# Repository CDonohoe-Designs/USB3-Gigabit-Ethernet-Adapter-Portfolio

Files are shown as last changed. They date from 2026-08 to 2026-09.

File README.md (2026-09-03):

# USB 5 Gbit/s to Gigabit Ethernet Adapter

LAN7800-based **USB 5 Gbit/s (USB 3.2 Gen 1, formerly USB 3.1 Gen 1)** to Gigabit Ethernet adapter designed in **Altium Designer** as a high-speed hardware and PCB design portfolio project.

<p align="center">
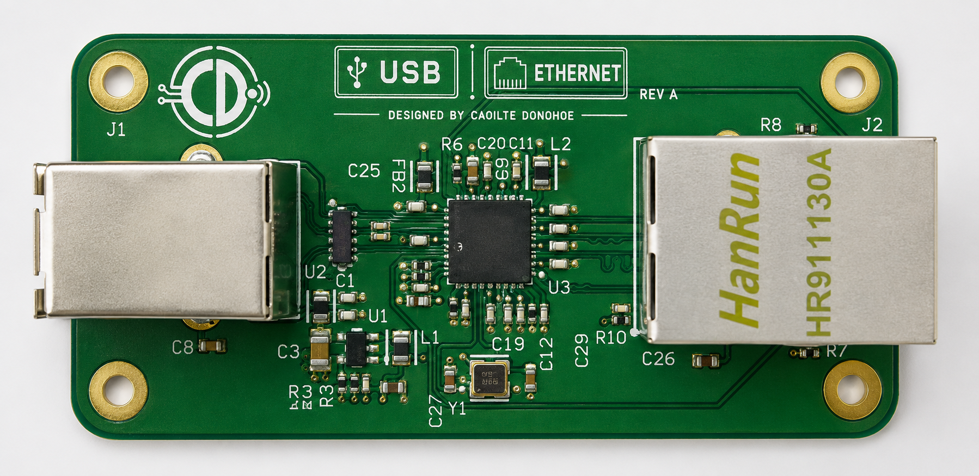
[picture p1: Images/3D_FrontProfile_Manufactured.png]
LAN7800 USB to Gigabit Ethernet adapter 3D view
  
</p>

## 2-Minute Engineering Review

I designed this project as a complete **high-speed digital hardware exercise**, taking the design from architecture and schematic capture through controlled-impedance PCB layout, rule-driven verification and fabrication outputs.

### Engineering focus

- **High-speed interfaces** — USB 5 Gbit/s SuperSpeed, USB 2.0 and Gigabit Ethernet on the same board
- **Signal integrity** — 90 Ω USB and 100 Ω Ethernet differential-impedance targets
- **Return-path control** — continuous reference structure and deliberate avoidance of unnecessary layer transitions
- **Constraint-driven layout** — Altium net classes, differential-pair classes, matched-length rules and layer restrictions
- **Power integrity** — local decoupling and separate LAN7800 supply routing/pours
- **Protection / EMC intent** — ESD protection close to external interfaces and controlled current-return paths
- **Manufacturing readiness** — fabrication drawing, Gerber X2, NC Drill and final Altium DRC

### Quick review

- **[Complete schematic](Docs/LAN7800_USB_Ethernet_RevA_Schematic.pdf)**
- **[PCB top layout](Images/PCB_Layout_Top.PNG)**
- **[PCB bottom / power layout](Images/PCB_Layout_Bottom.PNG)**
- **[High-speed design rules](Images/Design_Rules/)**
- **[Final DRC result](Images/DRC.PNG)**
- **[Fabrication drawing](Docs/LAN7800_USB_Ethernet_RevA_Fabrication.PDF)**
- **[Editable Altium source](Hardware/Altium/)**

> **Current status:** schematic, PCB layout, design-rule verification and manufacturing outputs are complete. The repository presents the design and fabrication package as portfolio evidence rather than claiming physical product validation.

---

## Project Overview

I designed this board to convert a **USB 5 Gbit/s host connection** to **10/100/1000BASE-T Ethernet** using the Microchip **LAN7800** USB-to-Ethernet controller.

I developed the project to demonstrate the complete hardware design process rather than schematic capture alone, including component selection, power architecture, controlled-impedance routing, high-speed PCB constraints, grounding and return-path control, manufacturability rules, DRC, and fabrication documentation.

### Key design features

- Microchip **LAN7800** USB-to-Gigabit-Ethernet controller
- USB 2.0 and USB 5 Gbit/s SuperSpeed interfaces
- Gigabit Ethernet MDI interface to RJ45 MagJack
- **4-layer PCB** with dedicated internal reference structure
- **90 Ω differential impedance** target for USB
- **100 Ω differential impedance** target for Gigabit Ethernet
- Dedicated Altium **net classes, differential-pair classes and routing rules**
- Length matching and controlled pair spacing for high-speed interfaces
- Separate power routing/pours for the LAN7800 supply rails
- ESD/protection components positioned close to the external interfaces
- Fabrication drawing and manufacturing output preparation
- Final PCB checked using Altium DRC

## High-Speed Design Approach

I treated the PCB as a **high-speed design**, with the layout driven by signal-integrity and return-path requirements rather than by simple point-to-point connectivity.

The main design methods I used were:

- **Controlled impedance:** dedicated Altium impedance profiles were created for 90 Ω USB and 100 Ω Ethernet differential routing.
- **Differential-pair classes:** USB 2.0, USB SuperSpeed and Ethernet MDI signals were separated into dedicated classes so interface-specific constraints could be applied consistently.
- **Length matching:** matched-length rules were used to control skew within high-speed differential pairs, with separate Ethernet pair-to-pair matching constraints.
- **Continuous reference planes:** the high-speed signals are routed primarily on the outer signal layer over an adjacent solid reference plane.
- **Layer restrictions:** high-speed classes were constrained to intended routing layers to avoid unnecessary layer changes and reference-plane discontinuities.
- **Controlled spacing and clearance:** dedicated rules were used for pair geometry, pair-to-pair spacing and clearance from unrelated copper.
- **Via control:** separate via styles were defined for general and higher-current power routing.
- **Power integrity:** local power pours, short decoupling paths and large ground regions were used around the LAN7800 and its regulators.
- **Manufacturing constraints:** minimum annular ring, drilled-hole, solder-mask and silkscreen rules were included in the PCB rule set.
- **Rule-driven verification:** Altium's PCB Rules and Constraints system and DRC were used to check that the physical implementation remained consistent with the design intent.

## PCB Layout

### Top side

I used the top layer for the principal signal routing, including the USB and Ethernet differential interfaces and the LAN7800 support circuitry.

<p align="center">
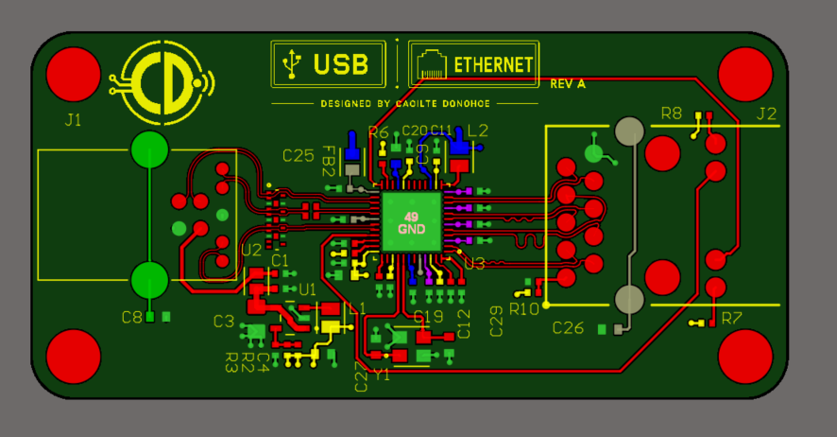
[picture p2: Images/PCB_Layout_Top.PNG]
Top PCB layout
  
</p>

### Bottom side — power and ground distribution

I used the bottom side for local power distribution together with a broad GND copper pour. The internal reference structure provides the primary high-speed return path.

<p align="center">
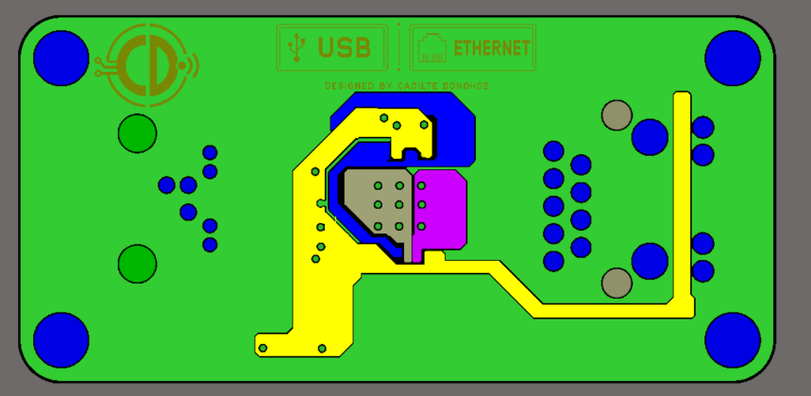
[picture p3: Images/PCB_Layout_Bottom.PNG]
Bottom PCB layout showing power and ground pours
  
</p>

## Schematic

The design is split into two functional sheets: **USB/power** and **LAN7800/Ethernet**.

<p align="center">
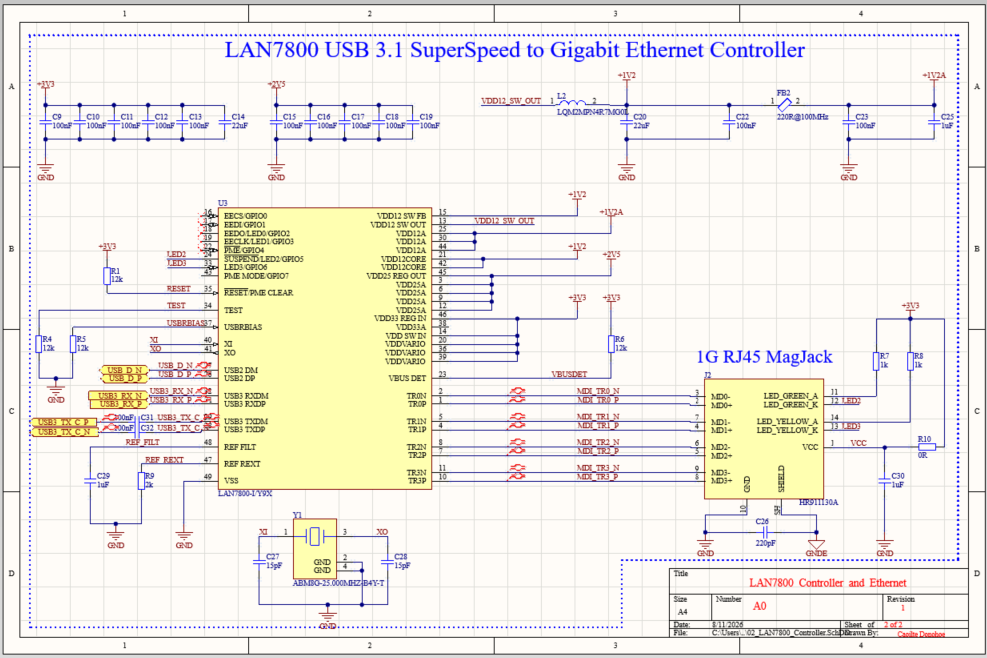
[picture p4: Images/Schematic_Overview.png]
LAN7800 and Ethernet schematic overview
  
</p>

<details>
<summary><b>View USB and power schematic overview</b></summary>

<p align="center">
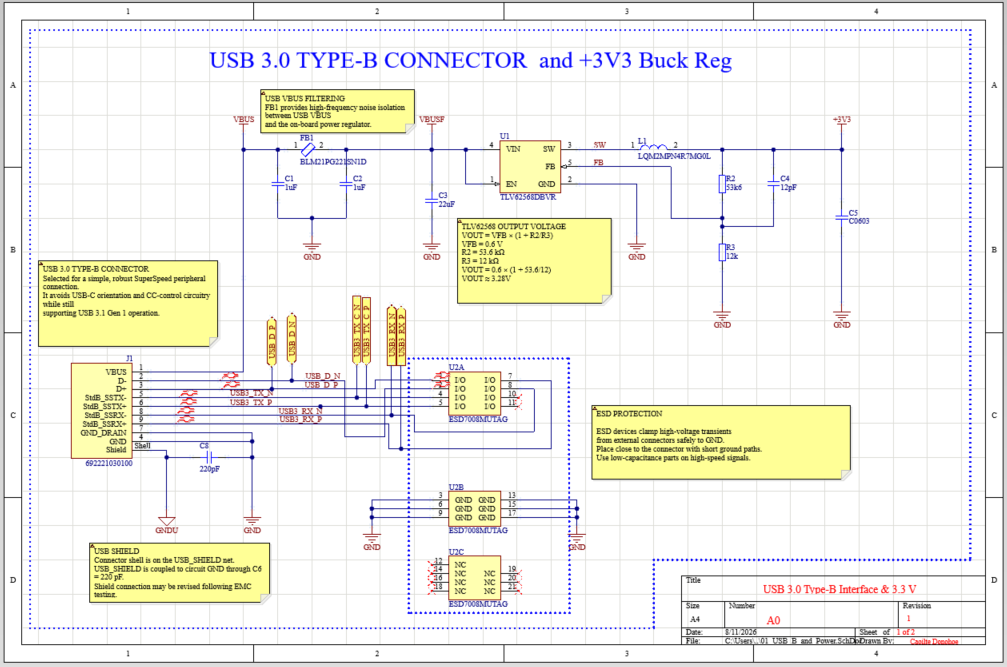
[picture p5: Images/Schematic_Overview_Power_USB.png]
USB and power schematic overview
  
</p>

</details>

**[View the complete schematic PDF](Docs/LAN7800_USB_Ethernet_RevA_Schematic.pdf)**

**[View the Rev A fabrication drawing](Docs/LAN7800_USB_Ethernet_RevA_Fabrication.PDF)**

**[Download the Rev A fabrication package](Manufacturing/LAN7800_USB_Ethernet_RevA_Fabrication.zip)**  
Gerber X2, NC Drill and fabrication documentation.

## Design Verification

I ran a final Altium **Design Rule Check** against the configured PCB rule set after completing the layout and copper pours. The final report shows **0 warnings and 0 rule violations**.

<p align="center">
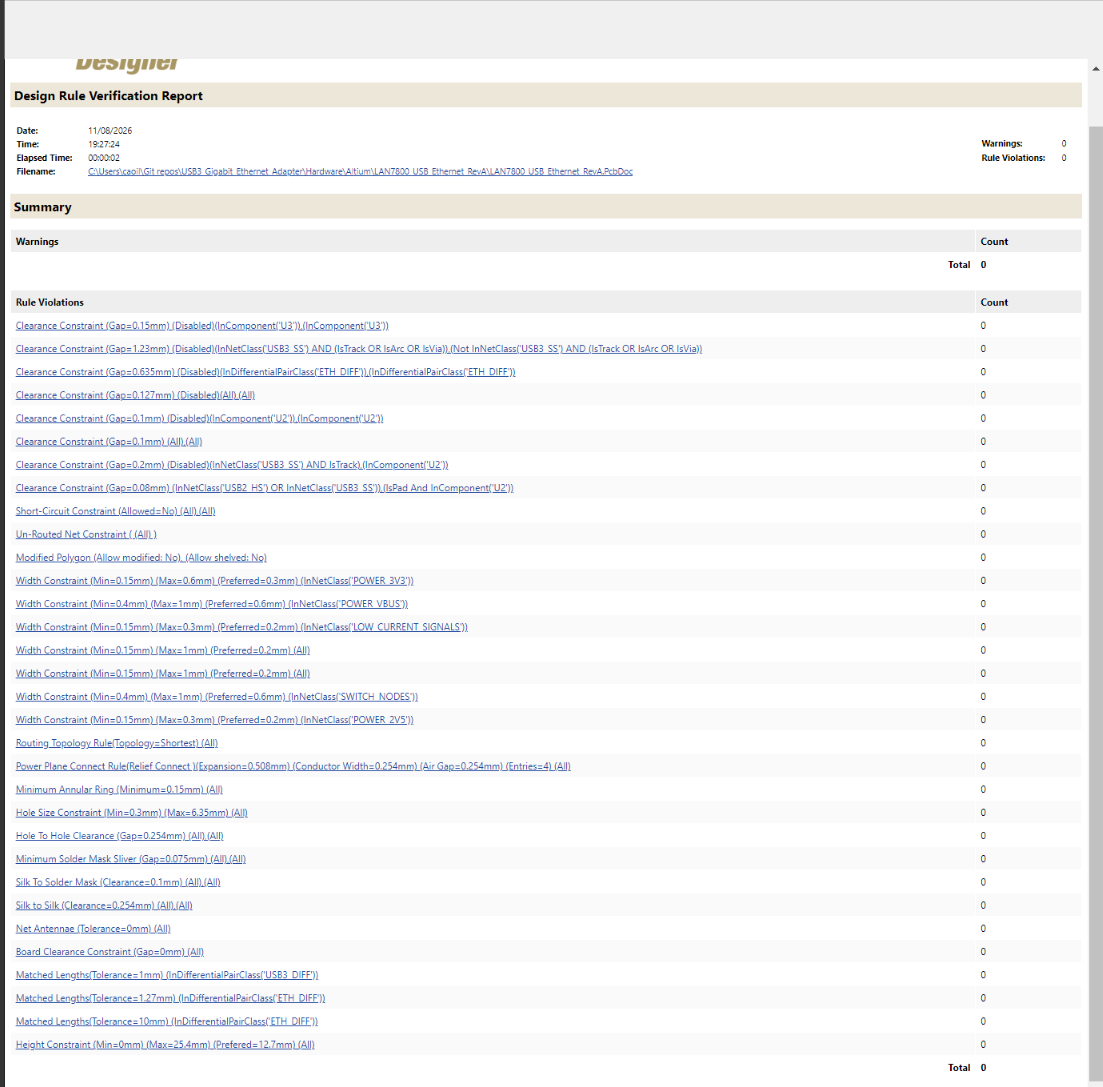
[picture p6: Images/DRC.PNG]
Altium final DRC report showing zero warnings and zero rule violations
  
</p>

## Altium Design Rules

I used a rule-driven approach rather than manually routing each interface with ad-hoc settings. Representative rule configuration is shown below.

<details>
<summary><b>View high-speed stack-up, impedance and rule configuration</b></summary>

### Layer stack

<p align="center">
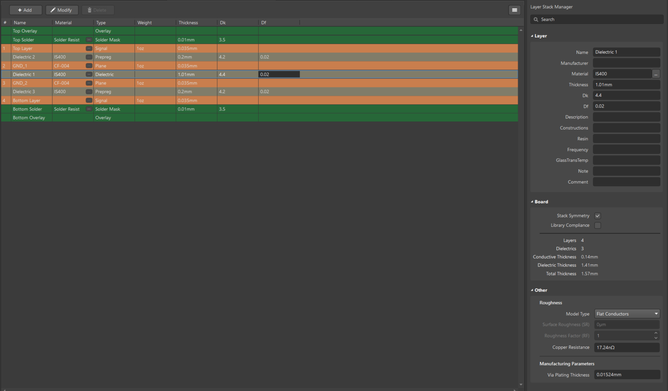
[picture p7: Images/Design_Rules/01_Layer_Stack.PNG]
4-layer PCB stack-up
  
</p>

### Controlled-impedance profiles

<p align="center">
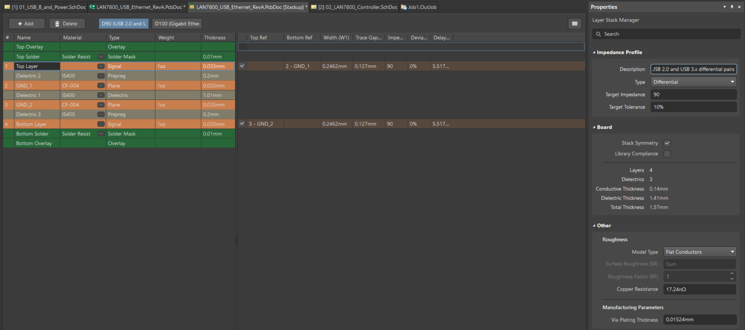
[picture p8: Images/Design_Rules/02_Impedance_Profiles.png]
USB and Ethernet impedance profiles
  
</p>

### Net classes

<p align="center">
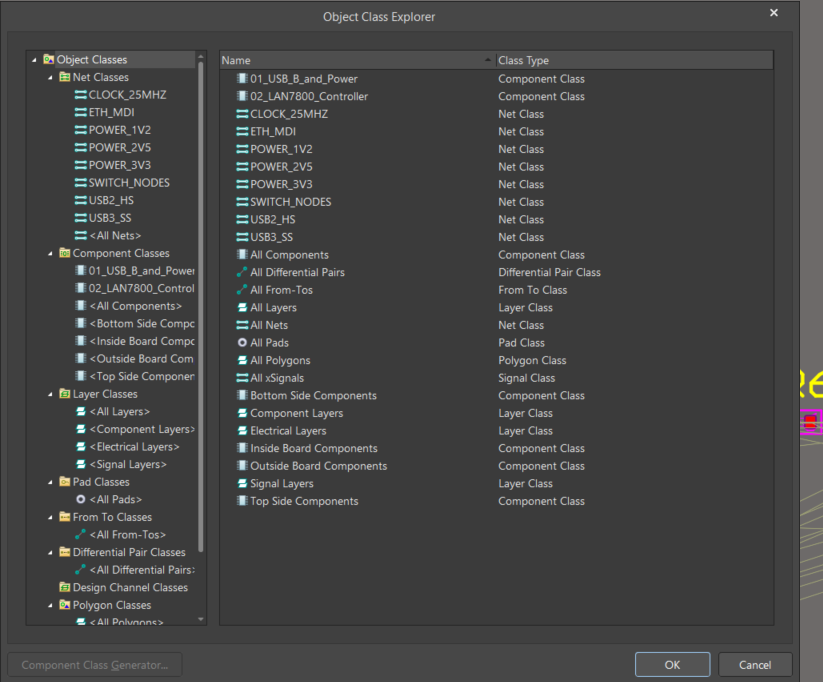
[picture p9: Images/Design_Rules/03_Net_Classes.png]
Altium net classes
  
</p>

### Differential-pair routing rules

<p align="center">
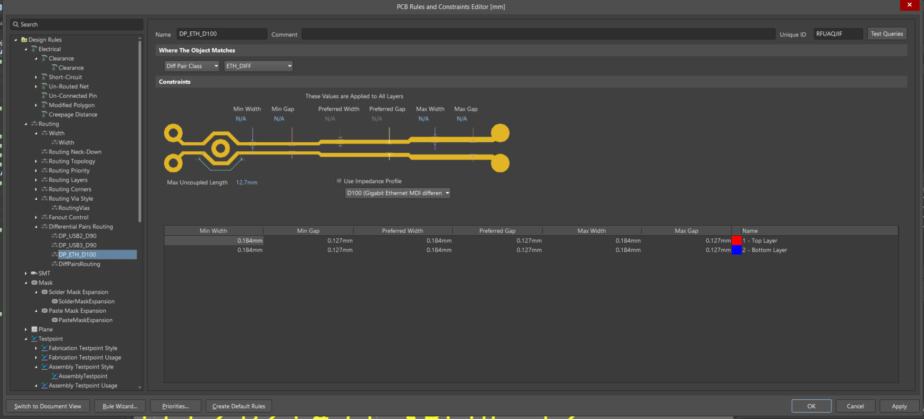
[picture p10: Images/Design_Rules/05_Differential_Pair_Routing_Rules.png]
Differential pair routing rules
  
</p>

### Matched-length rules

<p align="center">
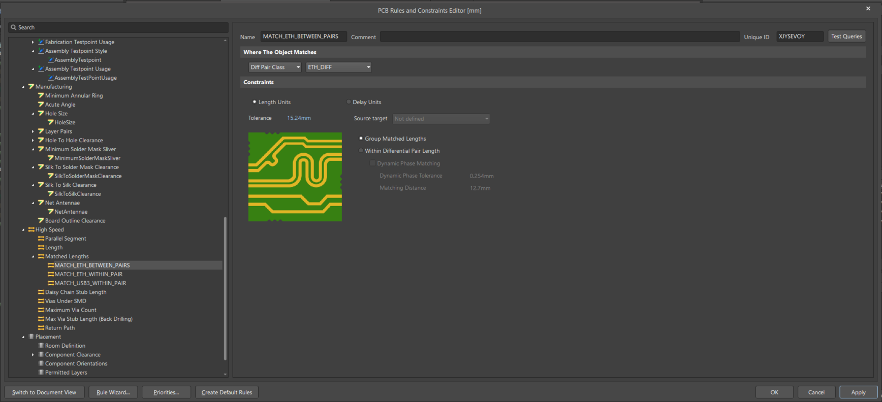
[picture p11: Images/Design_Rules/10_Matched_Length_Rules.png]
Matched length rules
  
</p>

</details>

## Source portability

I keep the repository focused on the project-owned source required to inspect the design: the Altium project, schematic sheets, PCB and project PCB library. Local-only references to downloaded component libraries, generated outputs and unrelated files are intentionally excluded from the portfolio project.

Manufacturer CAD packages are not redistributed here. The instantiated schematic and PCB data remain available in the project design files for review.

## Repository Contents

```text
Hardware/Altium/   Editable Altium schematic and PCB source
Docs/              Schematic and fabrication PDFs
Images/            PCB, schematic and selected design-rule images
Manufacturing/     Rev A Gerber X2 and NC Drill fabrication package
```

**Designed by Caoilte Donohoe**

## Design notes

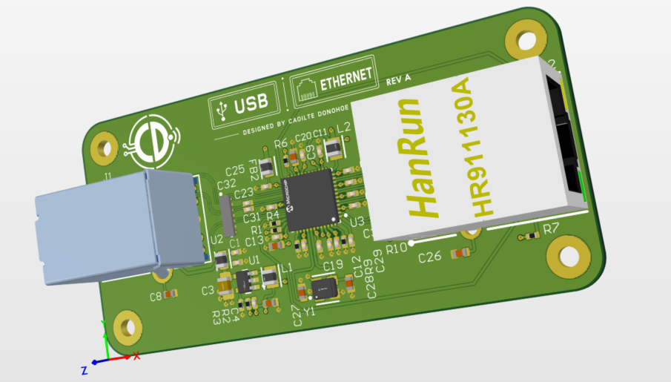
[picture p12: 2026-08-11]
Images/PCB_3D.PNG

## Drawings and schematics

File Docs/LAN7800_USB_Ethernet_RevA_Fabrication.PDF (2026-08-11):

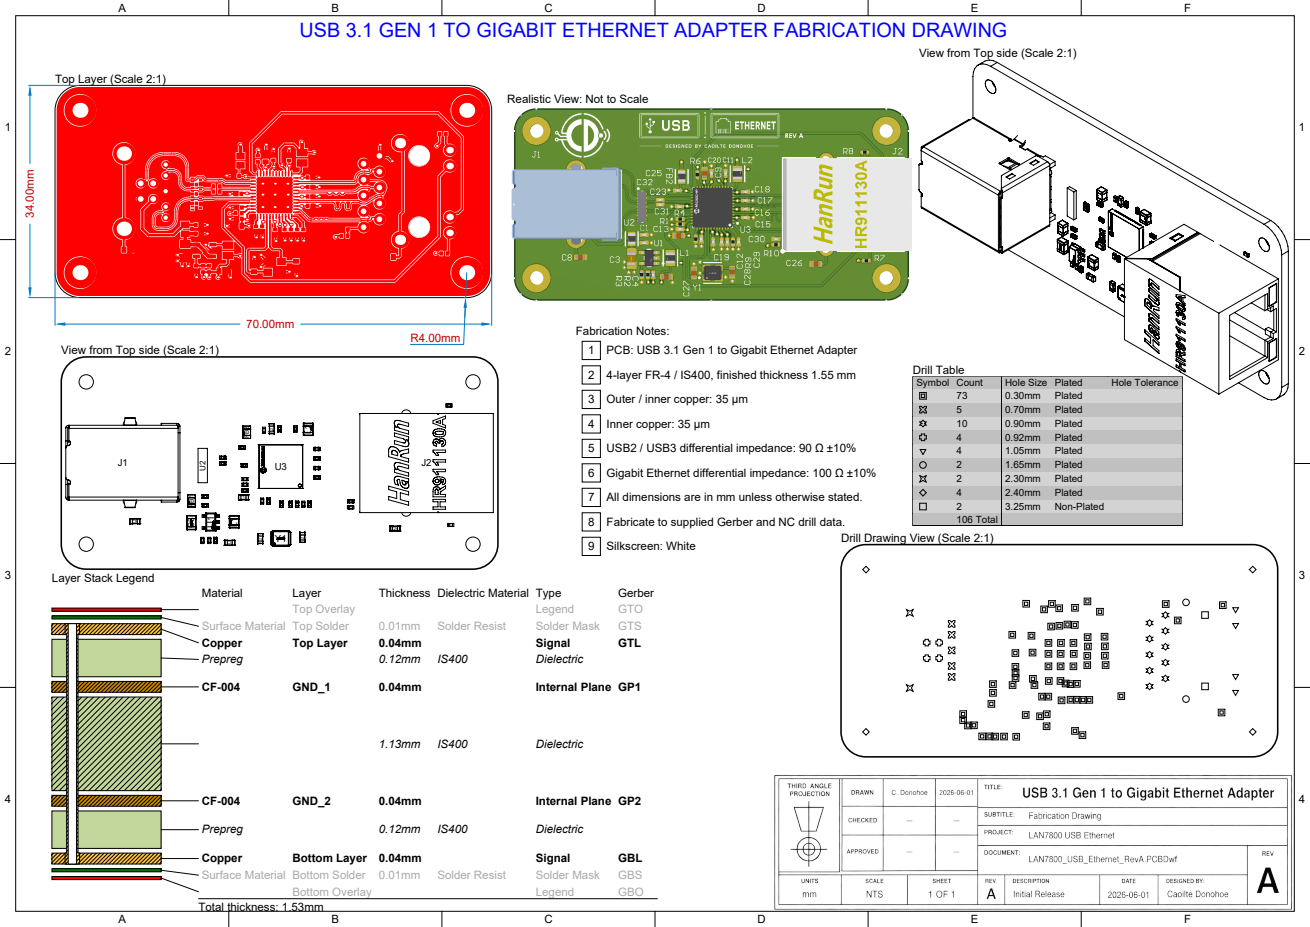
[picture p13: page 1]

USB 3.1 GEN 1 TO GIGABIT ETHERNET ADAPTER FABRICATION DRAWING

View from Top side (Scale 2:1)

Realistic View: Not to Scale

Symbol | Count | Hole Size | Plated | Hole Tolerance

73 | 0.30mm | Plated
5 | 0.70mm | Plated
10 | 0.90mm | Plated
4 | 0.92mm | Plated

2 | 1.65mm | Plated
2 | 2.30mm | Plated
4 | 2.40mm | Plated
2 | 3.25mm | Non-Plated
106 Total

Drill Drawing View (Scale 2:1)

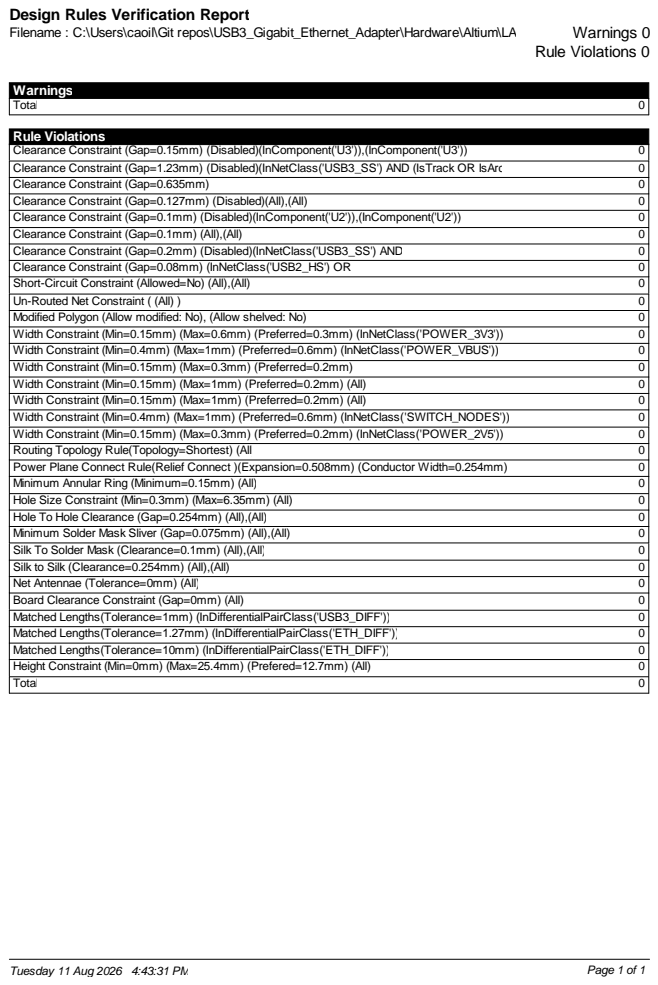
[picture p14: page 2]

Design Rules Verification Report

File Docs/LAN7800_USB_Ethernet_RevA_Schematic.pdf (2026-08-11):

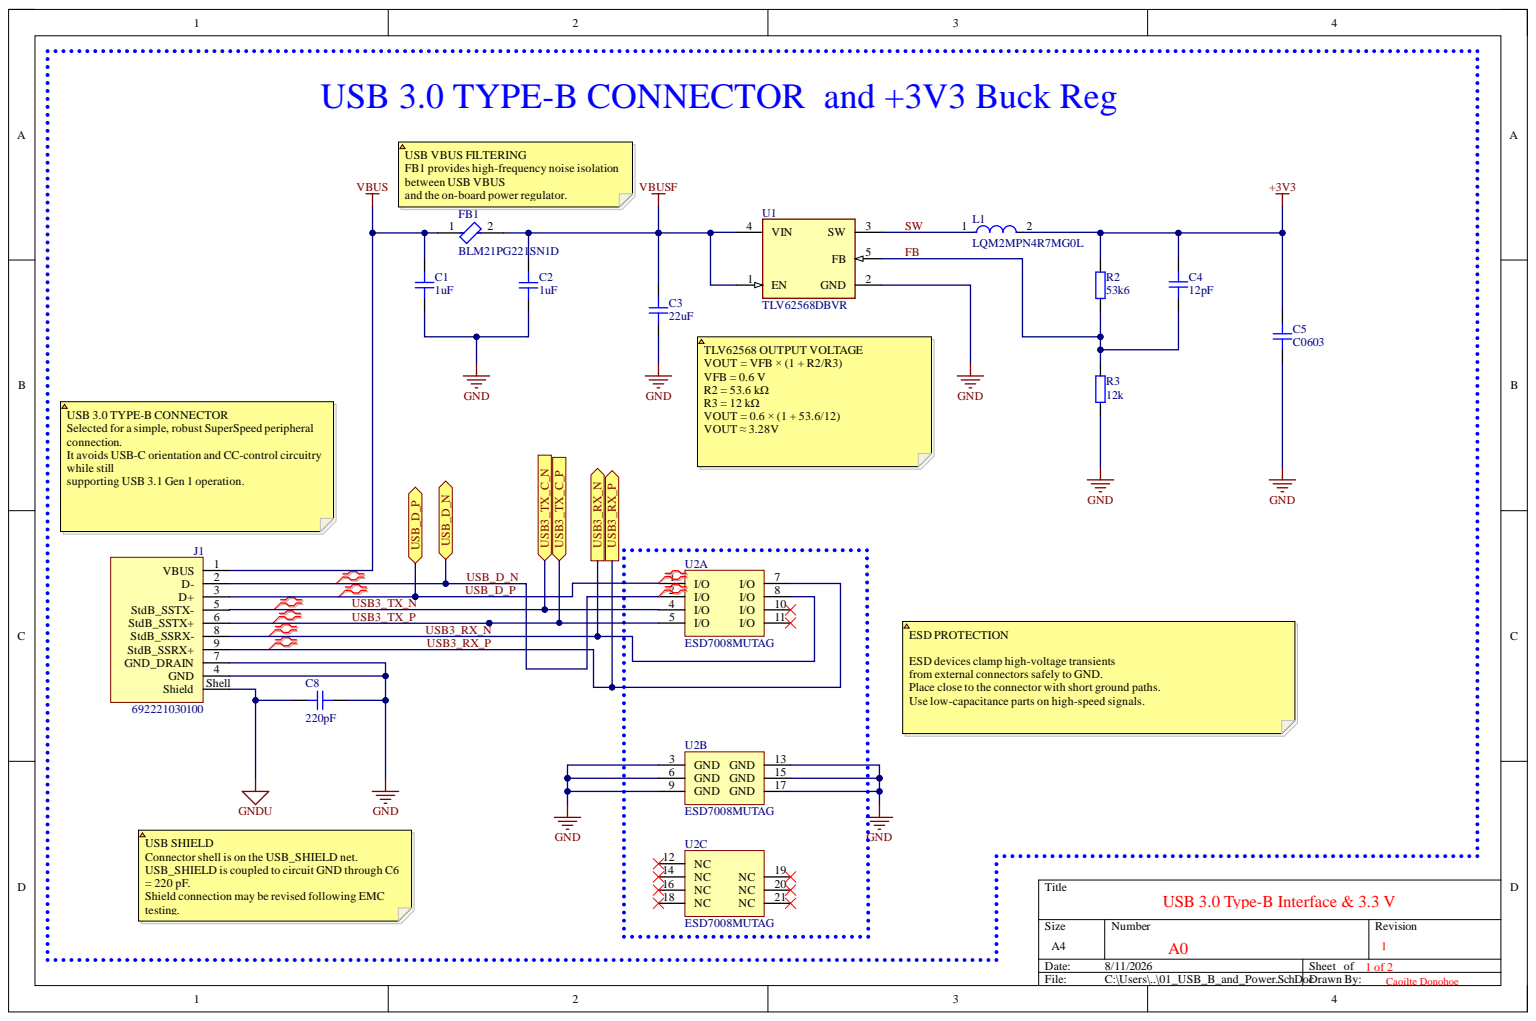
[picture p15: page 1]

USB 3.0 TYPE-B CONNECTOR and +3V3 Buck Reg

3 | USB_ D _P | | | 2 | | 8
5 USB3 _ T X_N | | | 4 | | 1 0
6 USB3 _ T X_P | | | 5 | | 1 1
8 USB3 _RX _N
9 USB3 _RX _P | | ESD 7 0 0 8MU TA

6 | 1 5
9 | 1 7

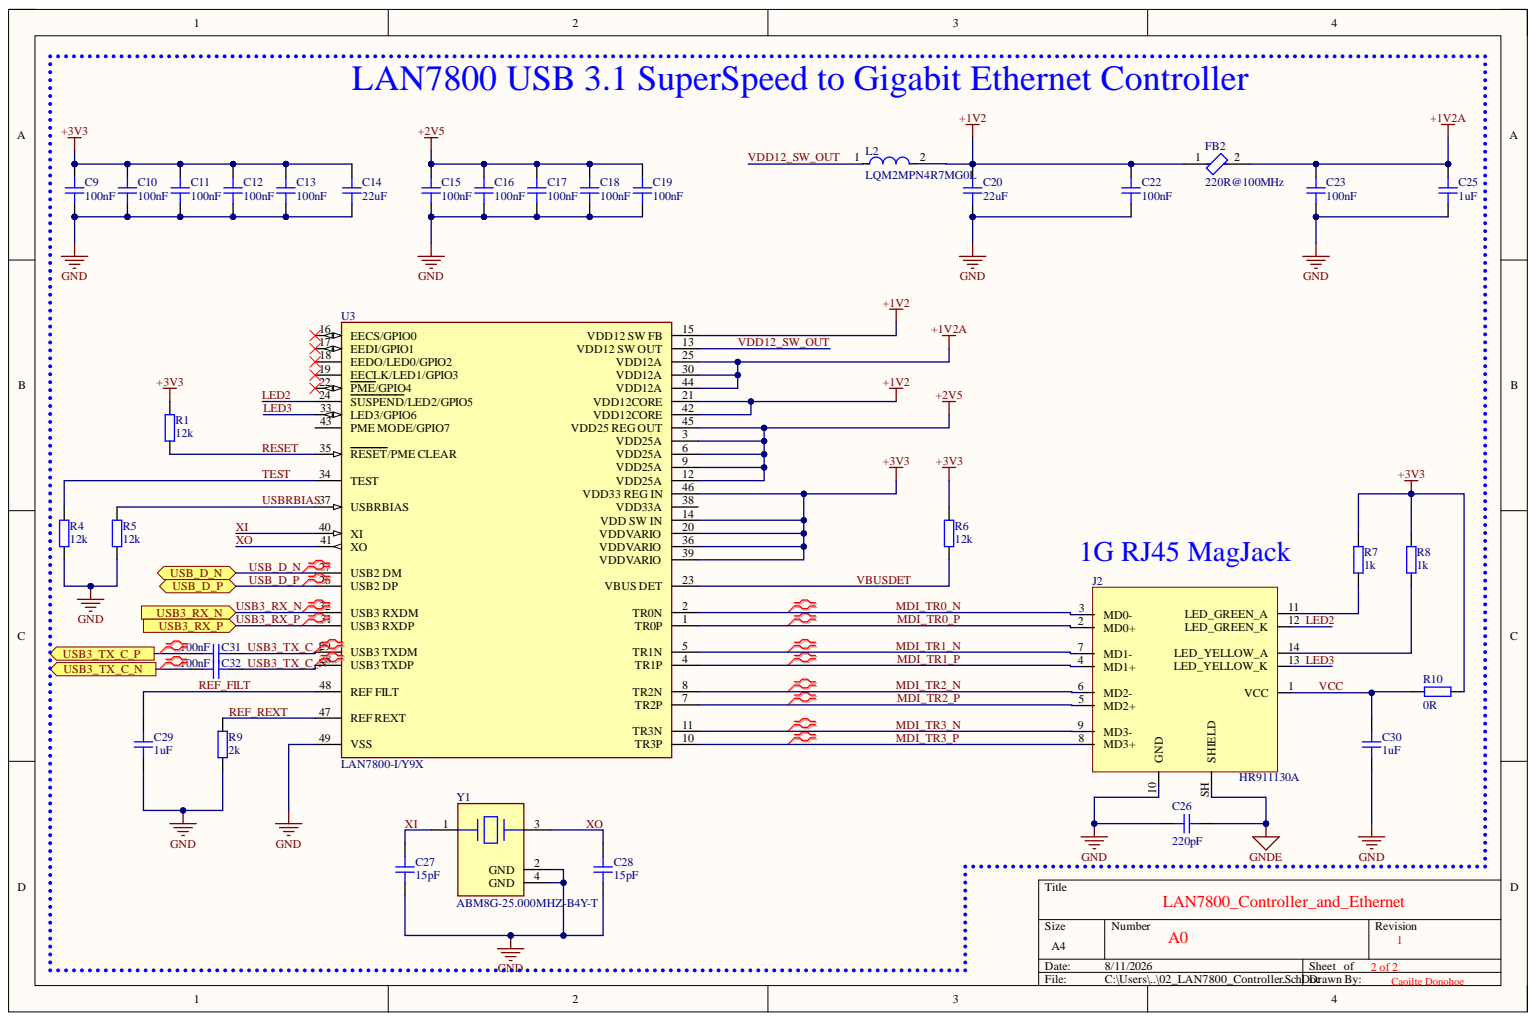
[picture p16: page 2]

LAN7800 USB 3.1 SuperSpeed to Gigabit Ethernet Controller

REF_REXT | REF REXT 47 | MDI_TR2_P

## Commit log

2026-08-11 Add portfolio README and design verification
    Add high-speed design overview, PCB and schematic images, Altium design-rule evidence and final DRC verification.
    [01_USB_B_and_Power.SchDoc, 02_LAN7800_Controller.SchDoc, LAN7800_USB_Ethernet_RevA.PcbDoc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]
2026-08-11 Add Altium design source
    [LAN7800_USB_Ethernet_RevA.PcbDoc, LAN7800_USB_Ethernet_RevA.PrjPcb]
2026-08-11 Add Rev A fabrication package
    Add final Gerber X2, NC Drill and fabrication documentation as a single manufacturing package.
2026-08-23 Modernise USB naming and tighten portfolio README
2026-10-10 Add Rev A BOM and component placement files
2026-10-10 Document Rev A BOM CPL and fabrication handoff in portfolio README
2026-10-10 Replace fabrication ZIP with Rev A Gerber and drill files
2026-10-10 Update manufacturing links for flattened Gerber and drill layout
2026-10-19 Correct BOM checksum in Rev 1.0 document-control register
